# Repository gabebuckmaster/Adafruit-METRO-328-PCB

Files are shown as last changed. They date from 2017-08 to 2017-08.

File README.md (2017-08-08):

# Stanford-EE-Metro-Mini

Microchip/Atmel generously donated ATMega328 chips for use in Stanford Electrical Engineering courses. This fork of the Adafruit Metro (Mini) repository contains the design files for our build of the Metro Mini using these donated components.

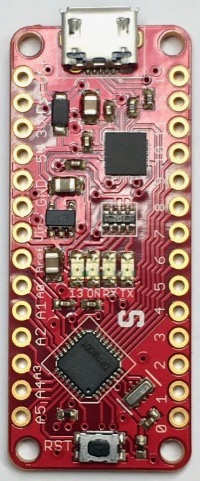
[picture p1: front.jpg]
Front
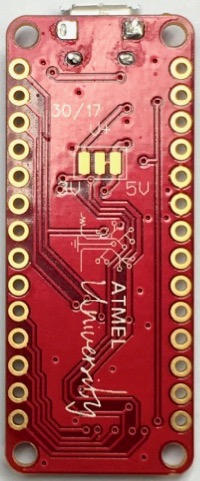
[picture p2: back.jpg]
Back
  

##*PCB files for the Adafruit METRO 328*

*Format is EagleCAD schematic and board layout*

*For more details, check out the product page at*

  * https://www.adafruit.com/products/2466

*Adafruit invests time and resources providing this open source design, please support Adafruit and open-source hardware by purchasing products from Adafruit!*

*Designed by Adafruit Industries.*

*Creative Commons Attribution, Share-Alike license, check license.txt for more information. Derivative of "Arduino UNO R3 Reference design" (http://www.arduino.cc/en/Main/ArduinoBoardUno)*

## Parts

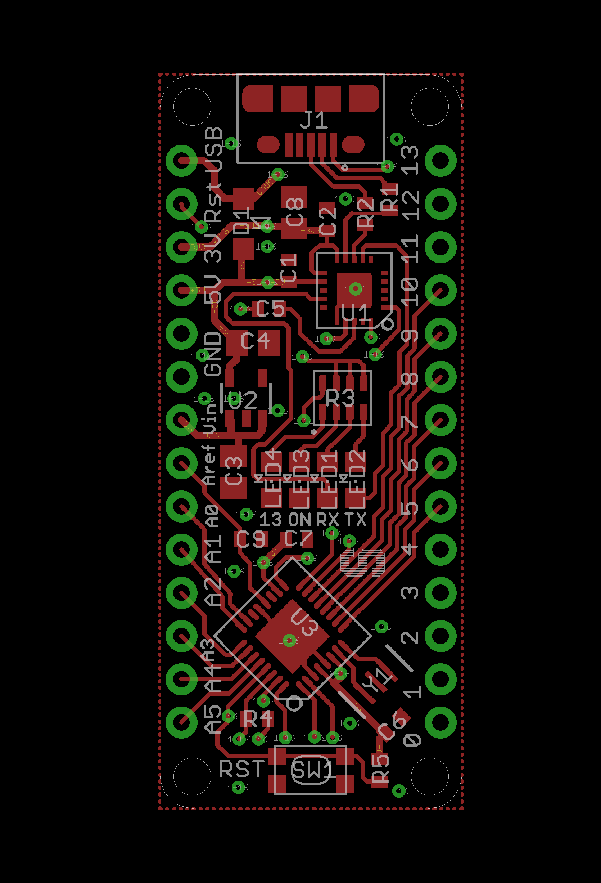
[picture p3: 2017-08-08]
component_placement.png

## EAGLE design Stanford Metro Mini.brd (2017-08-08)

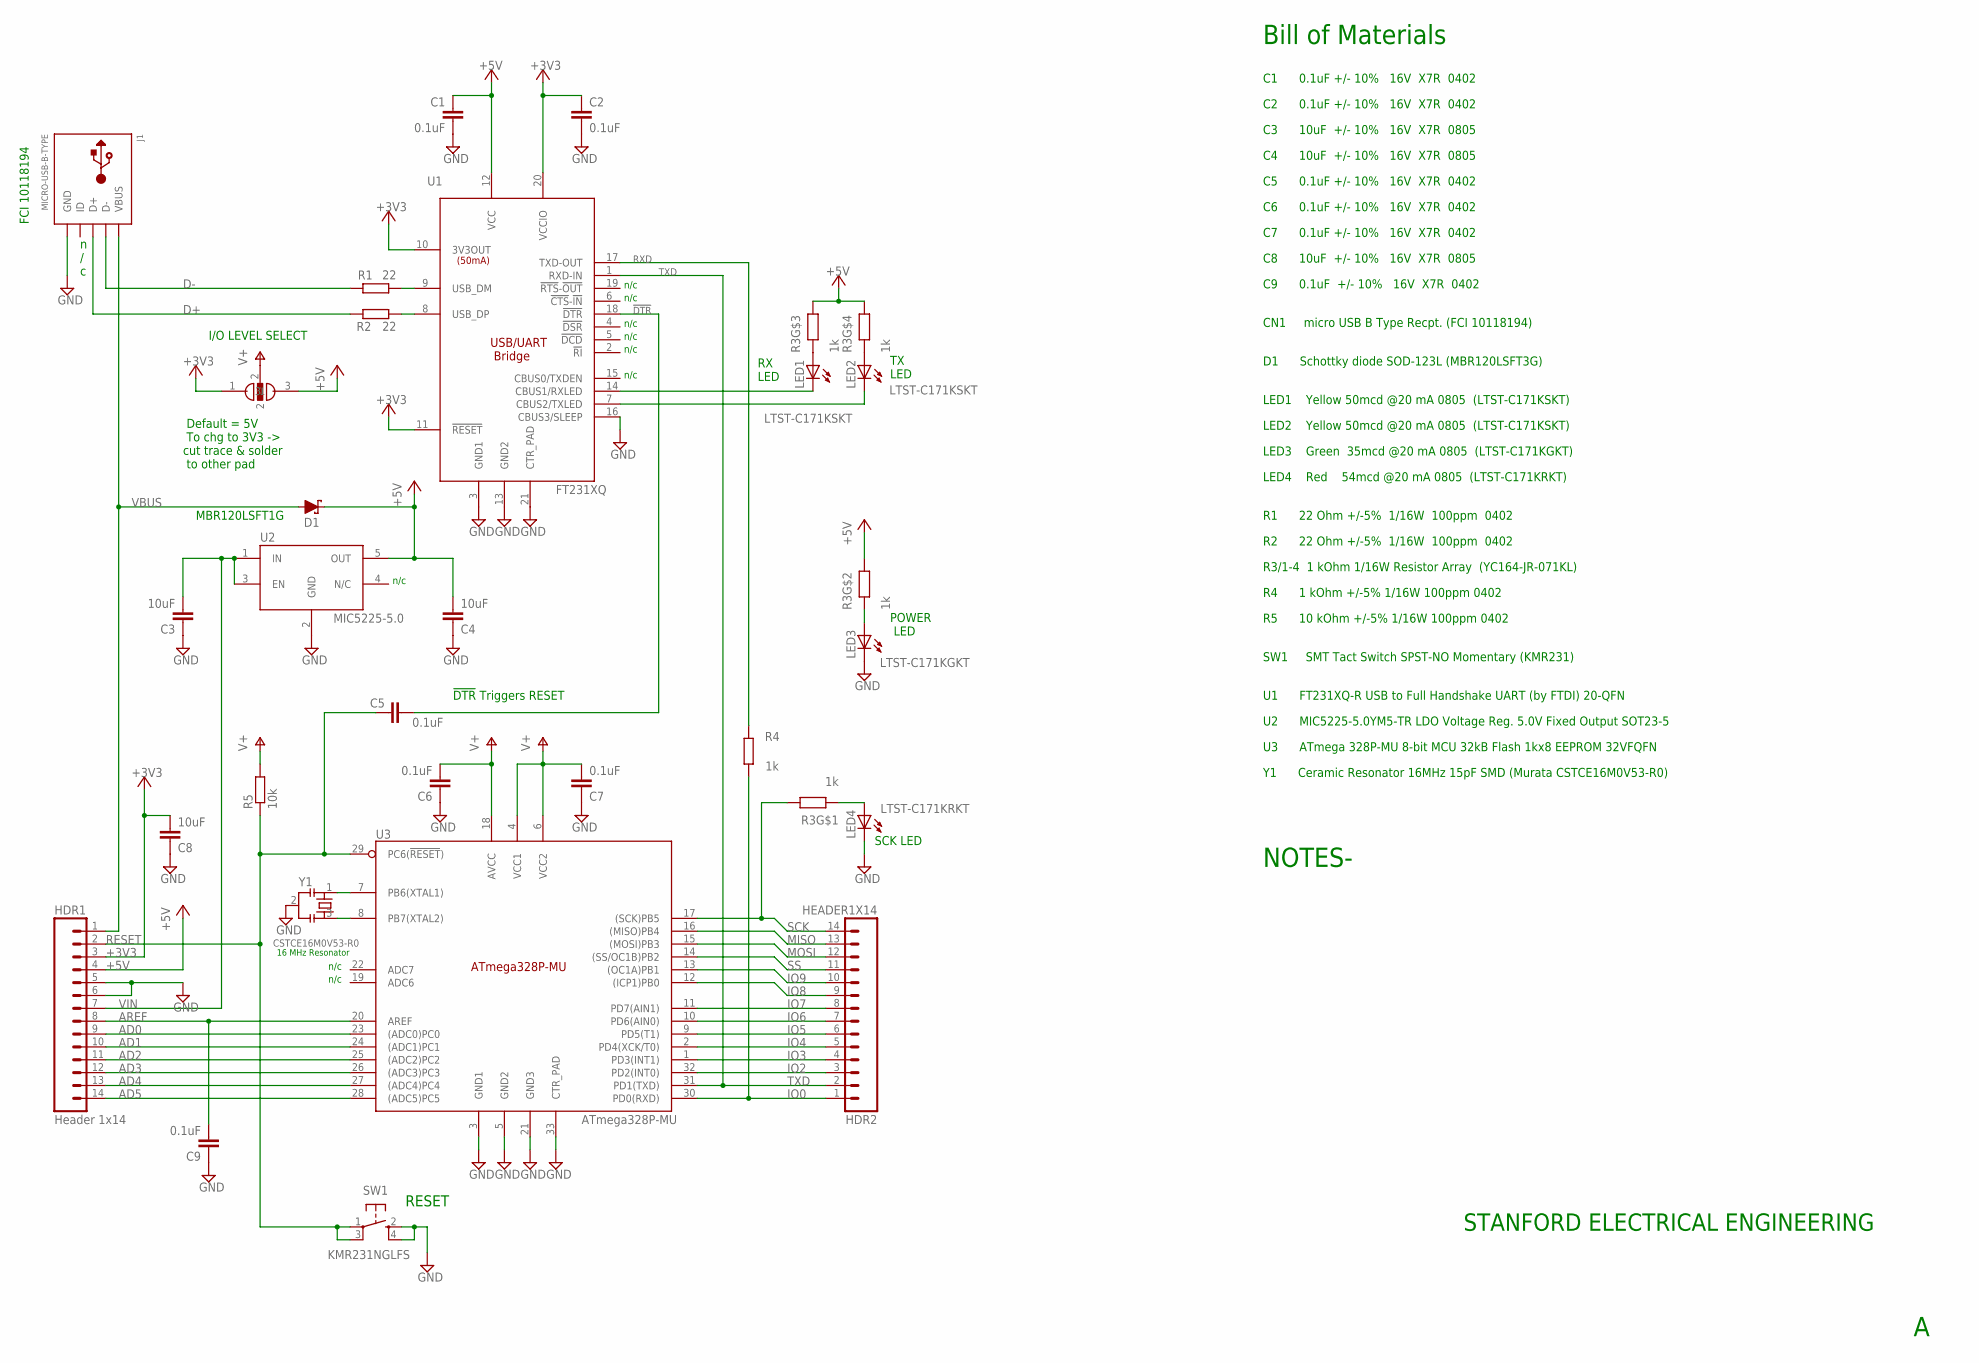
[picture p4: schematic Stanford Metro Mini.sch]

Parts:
C1, C2, C5, C6, C7, C9: 0.1uF; C0402
C3, C4, C8: 10uF; C0805
D1: SCHOTTKY; SOD123
HDR1: Header 1x14; 1X14
HDR2: HEADER1X14; 1X14
J1: MICRO-USB-B-TYPE; 10118194-MICRO-USB
LED1, LED2: LTST-C171KSKT; CHIPLED_0805
LED3: LTST-C171KGKT; CHIPLED_0805
LED4: LTST-C171KRKT; CHIPLED_0805
R1, R2: 22; R0402
R3: 1k; R-ARRAY
R4: 1k; R0402
R5: 10k; R0402
SW1: KMR231NGLFS; KMR2
U1: FT231XQ; QFN20
U2: MIC5225-5.0; SOT23-5
U3: ATmega328P-MU; VQFN-32_CTR-PAD
U$1: V_SELECT
Y1: CSTCE16M0V53-R0; CSTCE

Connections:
!DTR: C5.2, U1.18 (!DTR!)
+3V3: C2.1, C8.2, HDR1.3, U1.10 (3V3OUT), U1.11 (!RESET!), U1.20 (VCCIO), U$1.1
+5V: C1.1, C4.2, D1.1 (C), HDR1.4, R3.2B (B), R3.3B (B), R3.4B (B), U1.12 (VCC), U2.5 (OUT), U$1.3
AD0: HDR1.9, U3.23 ((ADC0)PC0)
AD1: HDR1.10, U3.24 ((ADC1)PC1)
AD2: HDR1.11, U3.25 ((ADC2)PC2)
AD3: HDR1.12, U3.26 ((ADC3)PC3)
AD4: HDR1.13, U3.27 ((ADC4)PC4)
AD5: HDR1.14, U3.28 ((ADC5)PC5)
AREF: C9.2, HDR1.8, U3.20 (AREF)
D+: J1.3 (D+), R2.1
D-: J1.2 (D-), R1.1
GND: C1.2, C2.2, C3.1, C4.1, C6.1, C7.1, C8.1, C9.1, HDR1.5, HDR1.6, J1.5 (GND), LED3.C, LED4.C, SW1.2 (S), SW1.4 (S1), U1.3 (GND1), U1.13 (GND2), U1.16 (CBUS3/SLEEP), U1.21 (CTR_PAD), U2.2 (GND), U3.3 (GND1), U3.5 (GND2), U3.21 (GND3), U3.33 (CTR_PAD), Y1.2
IO0: HDR2.1, R4.1, U3.30 (PD0(RXD))
IO2: HDR2.3, U3.32 (PD2(INT0))
IO3: HDR2.4, U3.1 (PD3(INT1))
IO4: HDR2.5, U3.2 (PD4(XCK/T0))
IO5: HDR2.6, U3.9 (PD5(T1))
IO6: HDR2.7, U3.10 (PD6(AIN0))
IO7: HDR2.8, U3.11 (PD7(AIN1))
IO8: HDR2.9, U3.12 ((ICP1)PB0)
IO9: HDR2.10, U3.13 ((OC1A)PB1)
MISO: HDR2.13, U3.16 ((MISO)PB4)
MOSI: HDR2.12, U3.15 ((MOSI)PB3)
unnamed: LED1.A, R3.3A (A)
unnamed: LED3.A, R3.2A (A)
unnamed: R1.2, U1.9 (USB_DM)
unnamed: R2.2, U1.8 (USB_DP)
unnamed: LED2.A, R3.4A (A)
unnamed: LED4.A, R3.1A (A)
unnamed: U3.7 (PB6(XTAL1)), Y1.1
unnamed: U3.8 (PB7(XTAL2)), Y1.3
RESET: C5.1, HDR1.2, R5.1, SW1.1, SW1.3 (P1), U3.29 (PC6(!RESET!))
RXD: R4.2, U1.17 (TXD-OUT)
RX_LED: LED1.C, U1.14 (CBUS1/RXLED)
SCK: HDR2.14, R3.1B (B), U3.17 ((SCK)PB5)
SS: HDR2.11, U3.14 ((SS/OC1B)PB2)
TXD: HDR2.2, U1.1 (RXD-IN), U3.31 (PD1(TXD))
TX_LED: LED2.C, U1.7 (CBUS2/TXLED)
V+: C6.2, C7.2, R5.2, U3.4 (VCC1), U3.6 (VCC2), U3.18 (AVCC), U$1.2
VBUS: D1.2 (A), HDR1.1, J1.1 (VBUS)
VIN: C3.2, HDR1.7, U2.1 (IN), U2.3 (EN)

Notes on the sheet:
!DTR! Triggers RESET
n / c
SCK LED
TX LED
RX LED
POWER LED
16 MHz Resonator
Default = 5V To chg to 3V3 -> cut trace & solder to other pad
I/O LEVEL SELECT
MBR120LSFT1G
n/c
RESET
C1 0.1uF +/- 10% 16V X7R 0402
C2 0.1uF +/- 10% 16V X7R 0402
C3 10uF +/- 10% 16V X7R 0805
C4 10uF +/- 10% 16V X7R 0805
C5 0.1uF +/- 10% 16V X7R 0402
C6 0.1uF +/- 10% 16V X7R 0402
C7 0.1uF +/- 10% 16V X7R 0402
C8 10uF +/- 10% 16V X7R 0805
C9 0.1uF +/- 10% 16V X7R 0402
D1 Schottky diode SOD-123L (MBR120LSFT3G)
LED1 Yellow 50mcd @20 mA 0805 (LTST-C171KSKT)
LED2 Yellow 50mcd @20 mA 0805 (LTST-C171KSKT)
LED3 Green 35mcd @20 mA 0805 (LTST-C171KGKT)
LED4 Red 54mcd @20 mA 0805 (LTST-C171KRKT)
R1 22 Ohm +/-5% 1/16W 100ppm 0402
R3/1-4 1 kOhm 1/16W Resistor Array (YC164-JR-071KL)
R2 22 Ohm +/-5% 1/16W 100ppm 0402
R4 1 kOhm +/-5% 1/16W 100ppm 0402
R5 10 kOhm +/-5% 1/16W 100ppm 0402
CN1 micro USB B Type Recpt. (FCI 10118194)
SW1 SMT Tact Switch SPST-NO Momentary (KMR231)
U1 FT231XQ-R USB to Full Handshake UART (by FTDI) 20-QFN
U2 MIC5225-5.0YM5-TR LDO Voltage Reg. 5.0V Fixed Output SOT23-5
U3 ATmega 328P-MU 8-bit MCU 32kB Flash 1kx8 EEPROM 32VFQFN
Y1 Ceramic Resonator 16MHz 15pF SMD (Murata CSTCE16M0V53-R0)
Bill of Materials
STANFORD ELECTRICAL ENGINEERING
NOTES-

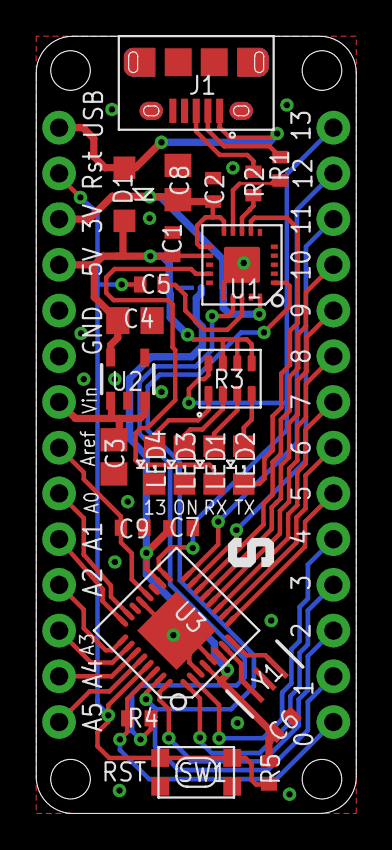
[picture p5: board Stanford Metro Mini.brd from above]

Board: 2 copper layers, 17.8 x 43.2 mm, 28 parts (1 on the bottom side), 42 nets.

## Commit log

2017-07-26 Initial Commit
    Initial commit of our version of the metro mini.
    [Metro Mini Rev A.brd, Metro Mini Rev A.sch, Metro THM+LDO Rev B.brd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]
2017-08-08 Fixed issues with first board run
    Fixed solder paste
    Adjusted QFN pad sizes
    Added the cam file to make regenerating gerbers easier
    Regenerated gerbers
    Generated SVGs of solder paste layer for laser cutting stencils
    [Stanford Metro Mini.brd, Stanford Metro Mini.sch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]
2017-08-08 Updated component placement guide and regenerated gerbers
    Updated component placement guide and regenerated gerbers
    [Stanford Metro Mini.brd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]
2017-08-08 Brightened pictures of board
    Brightened pictures of board
